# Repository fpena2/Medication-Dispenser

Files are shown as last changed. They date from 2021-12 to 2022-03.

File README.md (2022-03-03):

# Smart Medication Dispenser
Currently, doctors do not have a way to control when patients take their medications nor the amount of medications taken. As a solution to this problem, we introduce the Smart Medication Pill Dispenser. The project is composed of three main parts: an embedded system, a server, and a mobile user interface.
 
The embedded device, controlled by a Raspberry Pi, will feature compartment systems for controlled medicine delivery and a camera that works together with a high accuracy weight sensor that will verify when a patient has picked up their medication from the device.
 
The device will connect to a server which tracks timestamps and other user information and implements an artificial intelligence algorithm to detect, count, and potentially classify pills once they are released by the device. The server will communicate with the device for pill delivery timing, and with the mobile application to interface with patients and doctors.

The mobile frontend will allow doctors to receive a live image feed of the state of the medicine through a mobile application for iOS phones and look at timestamp logs of pill delivery and removal by the patient. Additionally, this application will allow doctors to manage medications and schedule when the medications are delivered to the patient. 

## Hardware Requirements 
+ Raspberry PI Zero W
  + with Raspberry Pi OS
+ 5VDC Stepper Motor (28BYJ-48) and ULN2003 Driver
+ Raspberry Pi Camera Module v1.3
+ Xiaoyztan White Light LED (Power: 1 Watt, Forward Current: 350mA, Forward Voltage: 3.0-3.2V)
  + 2N222 NPN Transistor 
  + One of each (10 Ω and 220 Ω resistor)

## Software Requirements
+ Python
+ Python libraries: `boto3`
  + Note: `picamera` and `RPi` are preinstalled in Raspberry Pi OS 

## Installation and How-to-Run
Simply clone this reposition into your Raspberry PI and execute the main file. 
```
$ Git clone https://github.com/fpena2/Medication-Dispenser.git
$ cd Medication-Dispenser
$ python3 run.py
```

## Pin-out and Connections 

1. Motor 1 & Motor 2
<p style="width: 50%;">
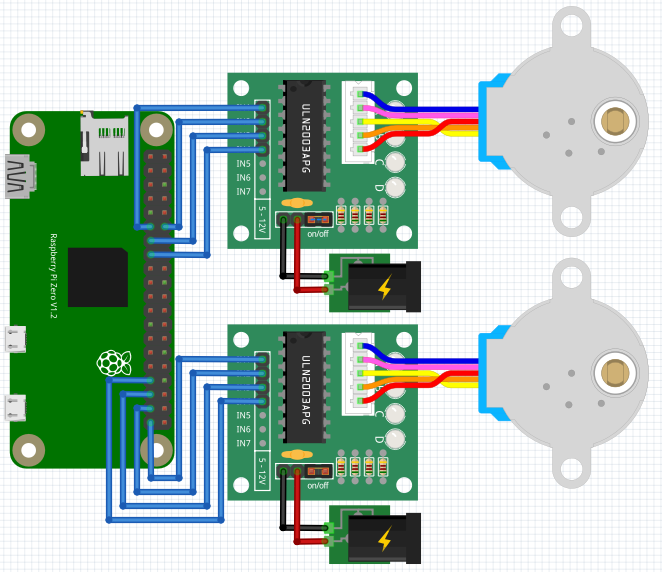
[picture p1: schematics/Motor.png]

</p>

2. LED 
<p style="width: 50%;">
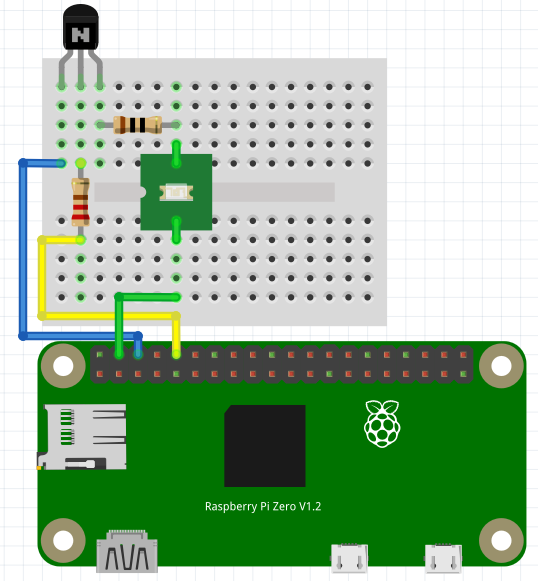
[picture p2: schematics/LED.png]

</p>

## Device Setup 
1. Motor Setup 
<p style="width: 50%;">
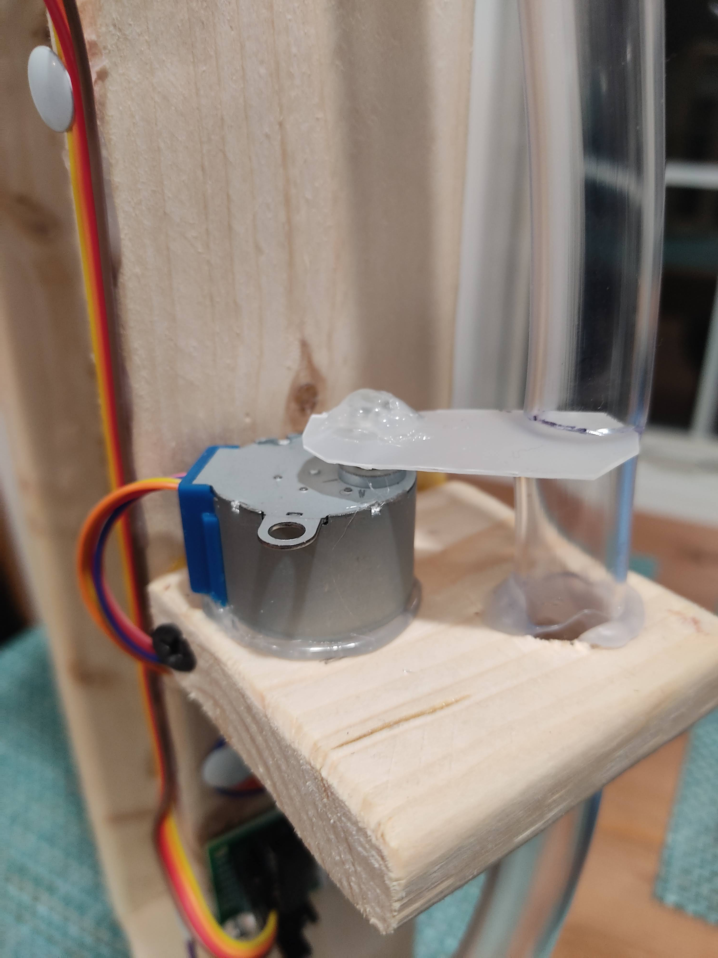
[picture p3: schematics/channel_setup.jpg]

</p>

2. Use Plexiglas for securing the platform 
<p style="width: 50%;">
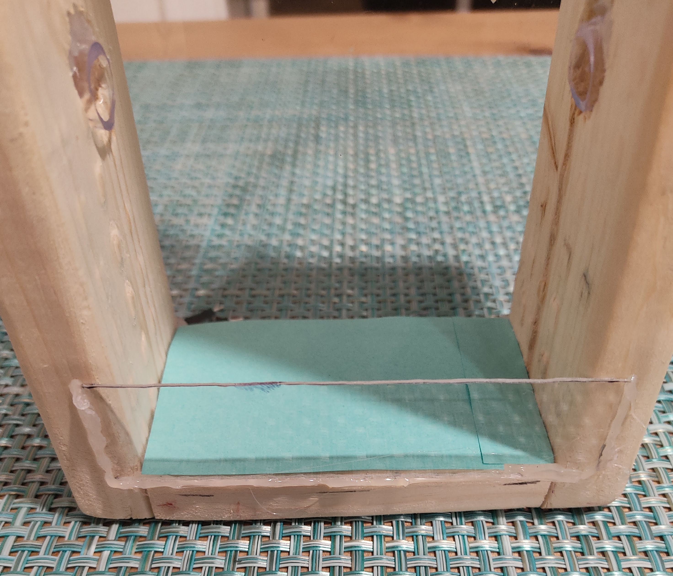
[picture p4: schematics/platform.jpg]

</p>

3. Device 
<p style="width: 50%;">
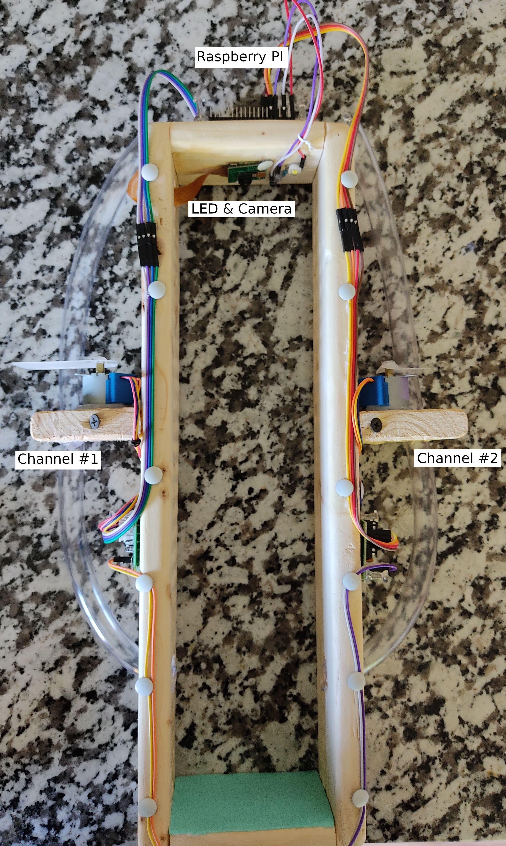
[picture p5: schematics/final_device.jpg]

</p>

## Contributing 🚀
If you would like to improve this system, simply fork the repo and make a pull request with your changes.

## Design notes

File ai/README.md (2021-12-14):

The AI component of this project is hosted entirely by AWS, using an S3 bucket and a Lambda function written in Python. The Lambda function containing the AI gets triggered when an image is uploaded to the 'images' folder of the bucket. 

Once triggered, the function converts the image to gray scale and applies blur and edge detection. Next, it converts from gray scale to binary using a set threshold, fills in any closed shapes, and counts the number of particles, (which are contiguous sections of white pixels) eliminating any which are outside size constraints. The particles are compared to a list of reference pills to identify objects. 

The AI outputs a list of pills on the platform, an updated color image with objects highlighted, and lists of pills released and removes along with additional data about device state.

## Installation

NOTE: It is easiest if all of these steps are performed within the same AWS account. If using multiple accounts, you will have to set up permissions across accounts using IAM roles. There are many tutorials in the AWS documentation to do this.

1. Create an S3 bucket with two sub-folders, 'images' and 'public'.

2. Copy the JSON files in the 'msg' folder of this repository to the 'public' folder in the bucket.

3. Create a Lambda function and copy the code from 'lambda_pill_detection.py'.

4. Add a trigger to the Lambda function when an object is uploaded to the 'images' folder of the S3 bucket. You should select the name of the bucket for the 'Bucket' field, 'All object create events' for the 'Event type' field, and put 'images/' in the optional prefix field.

5. Create a Lambda layer which includes `numpy` and openCV Python libraries. There are tutorials in AWS documentation and other online sources that walk through this process step-by-step. NOTE: You need Docker for this, so I recommend using Linux, as Docker does not behave well on Windows.

6. Upload this layer to an S3 bucket (it can be the same one you created earlier, so long as you don't upload the file to the 'images' folder). In the Lambda function's 'Code' tab, scroll down and press 'Add a layer', then add your custom layer. This will allow your function to utilize the cv2 and `numpy` libraries it needs for image processing.

7. Perform the necessary install steps for the device and the user interface, if desired. You can also run the AI manually without the other components by uploading images to the 'images' folder.

## How-to-Run

1. Update the pillDict in the Lambda function with the list of pills relevant to your use case. Entries should map a pill name to a dictionary containing the name, the pill size in pixels, the shape of the pill, and the color, as an RGBA vector.

2. The AI will automatically be triggered when a file is uploaded to the 'images' folder of the associated S3 bucket. Make sure only image files are uploaded here, as other file types will cause errors. AI output will be placed in the 'public' folder of the S3 bucket.

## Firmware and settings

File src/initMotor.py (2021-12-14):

import RPi.GPIO as GPIO
from time import sleep

# disable warnings
GPIO.setwarnings(False)

# Pin Configuration (GPIO)
chanList1 = [17, 18, 27, 22]  # right side or pill_1
chanList2 = [26, 19, 13, 6]  # lift side or pill_2

# Variables
delay = 0.001

# Rotation
rot_360 = 4096
rot_180 = int(rot_360 / 2)
rot_90 = int(rot_360 / 4)
rot_45 = int(rot_360 / 8)

# State
lock = 1
release = -1

# Step Motor Sequence
sequence = [
    [1, 0, 0, 1],
    [1, 0, 0, 0],
    [1, 1, 0, 0],
    [0, 1, 0, 0],
    [0, 1, 1, 0],
    [0, 0, 1, 0],
    [0, 0, 1, 1],
    [0, 0, 0, 1],
]


class motorController:
    def __init__(self, chanList):
        self.chanList = chanList
        GPIO.setmode(GPIO.BCM)
        GPIO.setup(self.chanList, GPIO.OUT)
        GPIO.output(self.chanList, GPIO.LOW)

    def reset(self):
        GPIO.setup(self.chanList, GPIO.OUT)
        GPIO.cleanup()

    # (+) Rotate caunter clockwise (looking from blue pastic marking)
    # (-) Rotate clockwise to release the pill
    def rotate(self, angle, direction):
        step = 0
        for _ in range(angle):
            for i in range(0, 4):
                sleep(delay)
                GPIO.output(self.chanList[i], sequence[step][i])
            step = (step + direction) % 8

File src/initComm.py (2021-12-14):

import boto3
from botocore.client import Config
import os


class commController:
    def __init__(self, bucket="", bucketFolder=""):
        self.bucket = bucket
        self.bucketFolder = bucketFolder

    def sendFile(self, imgPath):
        if os.path.isfile(imgPath):
            data = open(imgPath, "rb")
            name = os.path.basename(imgPath)
            self.startComm(name, data)

    def sendBulk(self, imgFolder):
        for img in os.listdir(self.imgFolder):
            if img.endswith(".jpg"):
                print(img)
                self.sendFile(img)

    def startComm(self, name, data):
        s3 = boto3.resource("s3")
        s3.Bucket(self.bucket).put_object(Key=self.bucketFolder + name, Body=data)

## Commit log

2021-09-29 Added camera functionality to driver
2021-11-02 Added led control
2021-11-04 Added LED support
2021-12-04 Fixing led
2021-12-04 fixing camera
2021-12-04 fix bug images have same name
    [initCam.py]
2021-12-05 Added second motor
2021-12-05 motor_2 bug fix - reverse logic
2021-12-06 motor object use & destroy
2021-12-06 debugging motor (dont reset obj)
2021-12-12 Organized repo
    [28BYJ-48-driver_and_motor-1.fzz, LED.fzz]
